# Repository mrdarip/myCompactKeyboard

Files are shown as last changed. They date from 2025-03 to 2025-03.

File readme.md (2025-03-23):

# my compact keyboard

## Description

## PCB
Here are pictures of my pcb:

| **Schematic** | **PCB** |
|---|---|
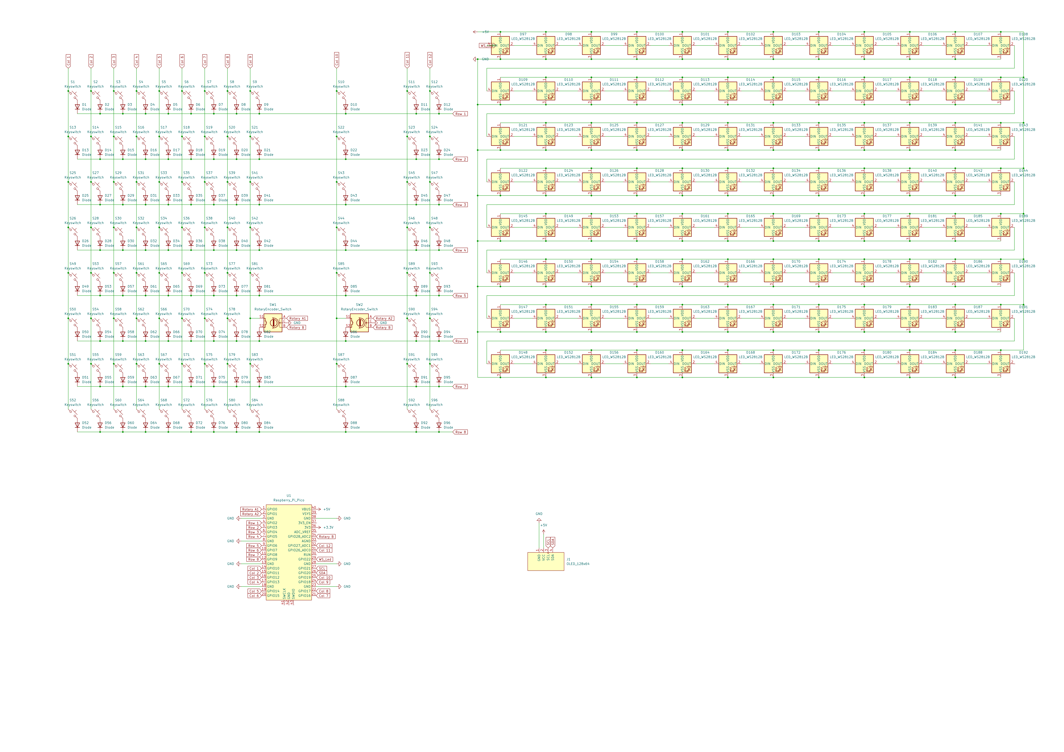
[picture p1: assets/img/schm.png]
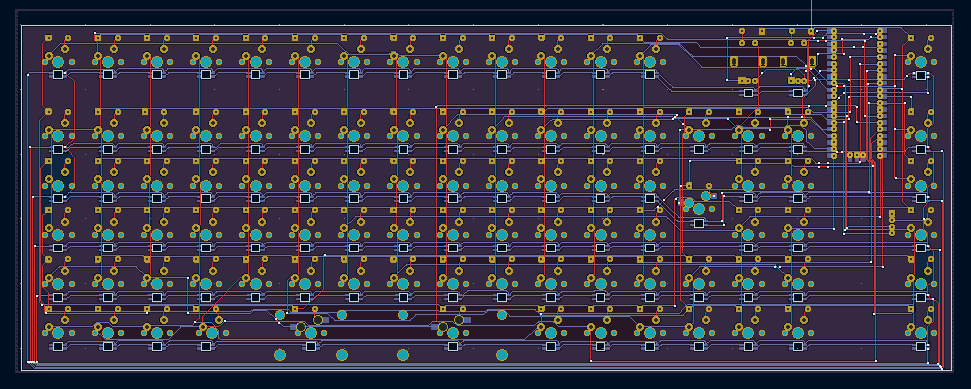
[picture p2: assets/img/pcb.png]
|||

Hope it looks good to you!

[x] I ran DRC and there are 0 errors

## CAD
Designed cases for it but my definitive one is made using svg's and openSCAD.

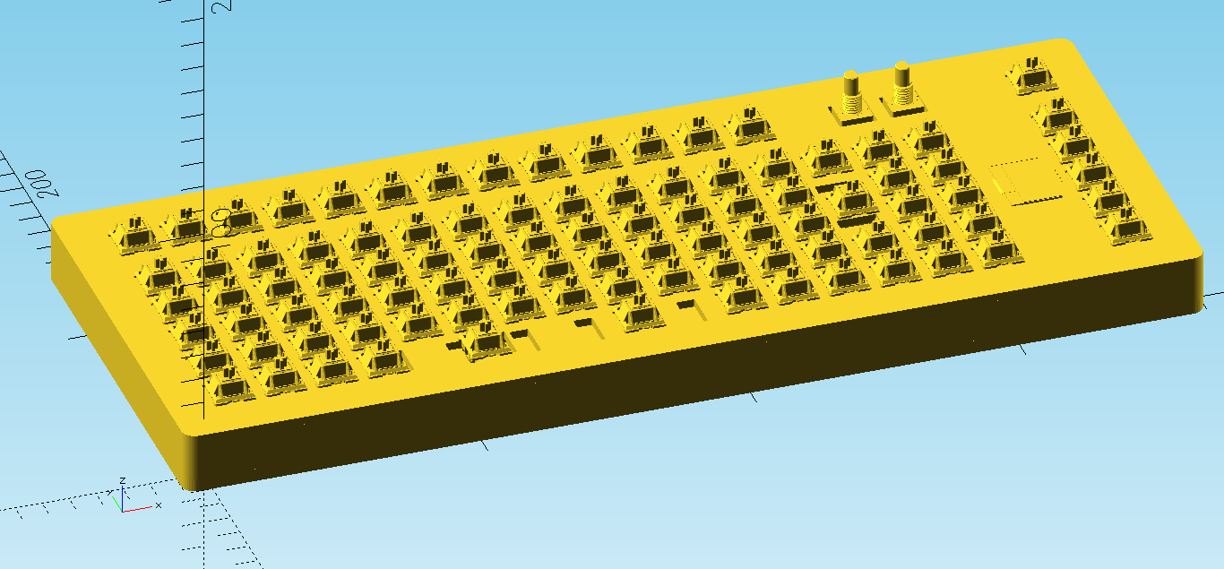
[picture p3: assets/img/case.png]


## Firmware

I wrote the firmware using kmk, it's pretty simple, but I'm proud of it!

## BOM
| **Quantity** | **Item** |
|---|---|
| 1 | Raspberry Pi Pico |
| 91 | Switches |
| 3 | Hotwap sockets |
| 96 | 1N4148 diodes |
| 96 | LED_WS2812B |
| 1 | SSD1306 |
| 2 | Rotary encoder |
| 1 | keycaps set |
| 3 | stabilizers |
| 4 | heatset inserts and their screws |

## IMPORTANT

- Dont send the 3d printed case  
    I'll print it myself so I'll get less customs fees.
- Don't send the soldering iron  
  I have one, less electronics waste, less customs fees.

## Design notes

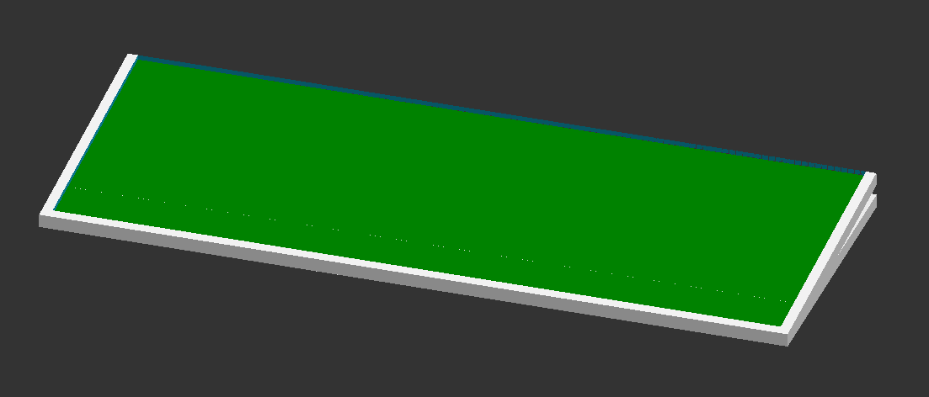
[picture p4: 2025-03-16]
assets/img/case2.png

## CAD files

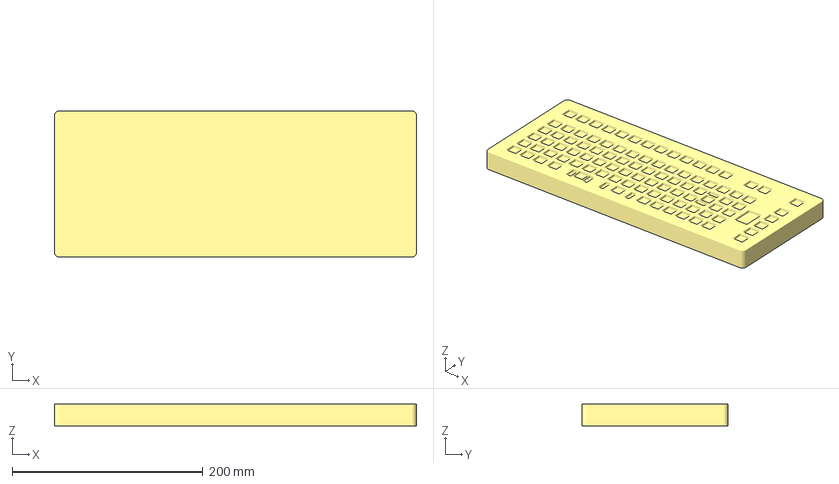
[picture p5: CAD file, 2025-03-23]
cad/caseByLayers.3mf
379.6 x 153.3 x 23.0 mm

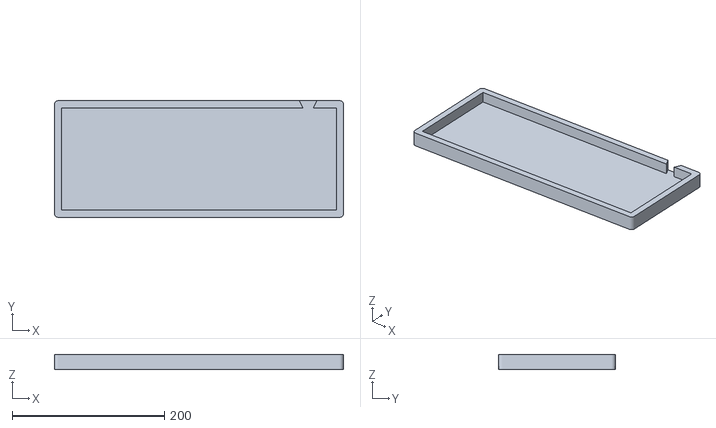
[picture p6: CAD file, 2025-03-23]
production/bottom.stl
379.6 x 153.3 x 20.0

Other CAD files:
pcb/freecadCase.FCStd
cad/case.scad
cad/caseByLayers.scad

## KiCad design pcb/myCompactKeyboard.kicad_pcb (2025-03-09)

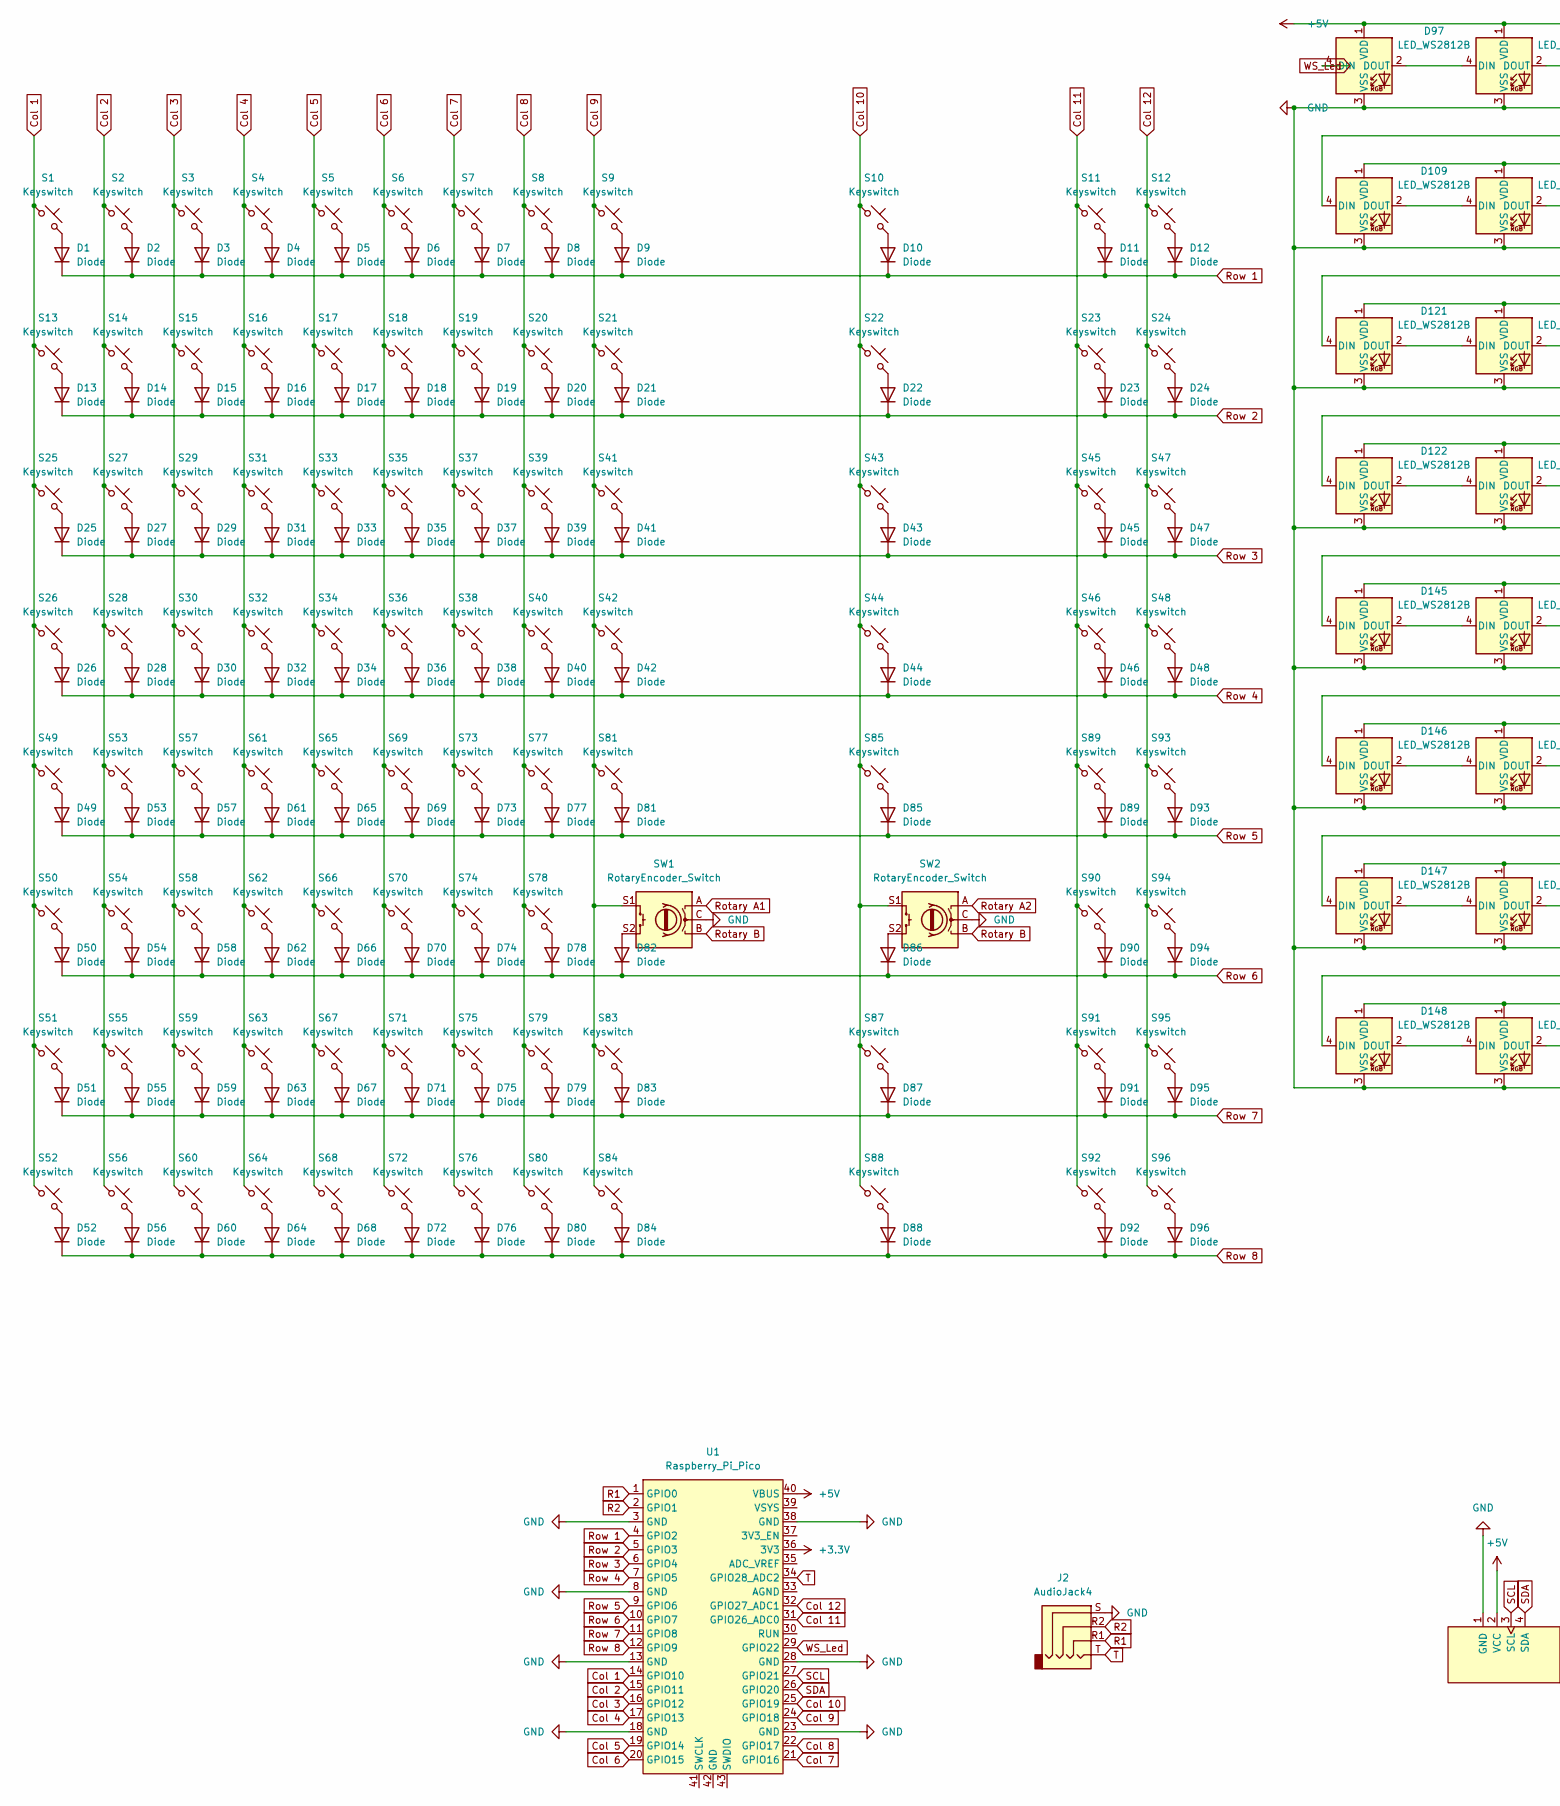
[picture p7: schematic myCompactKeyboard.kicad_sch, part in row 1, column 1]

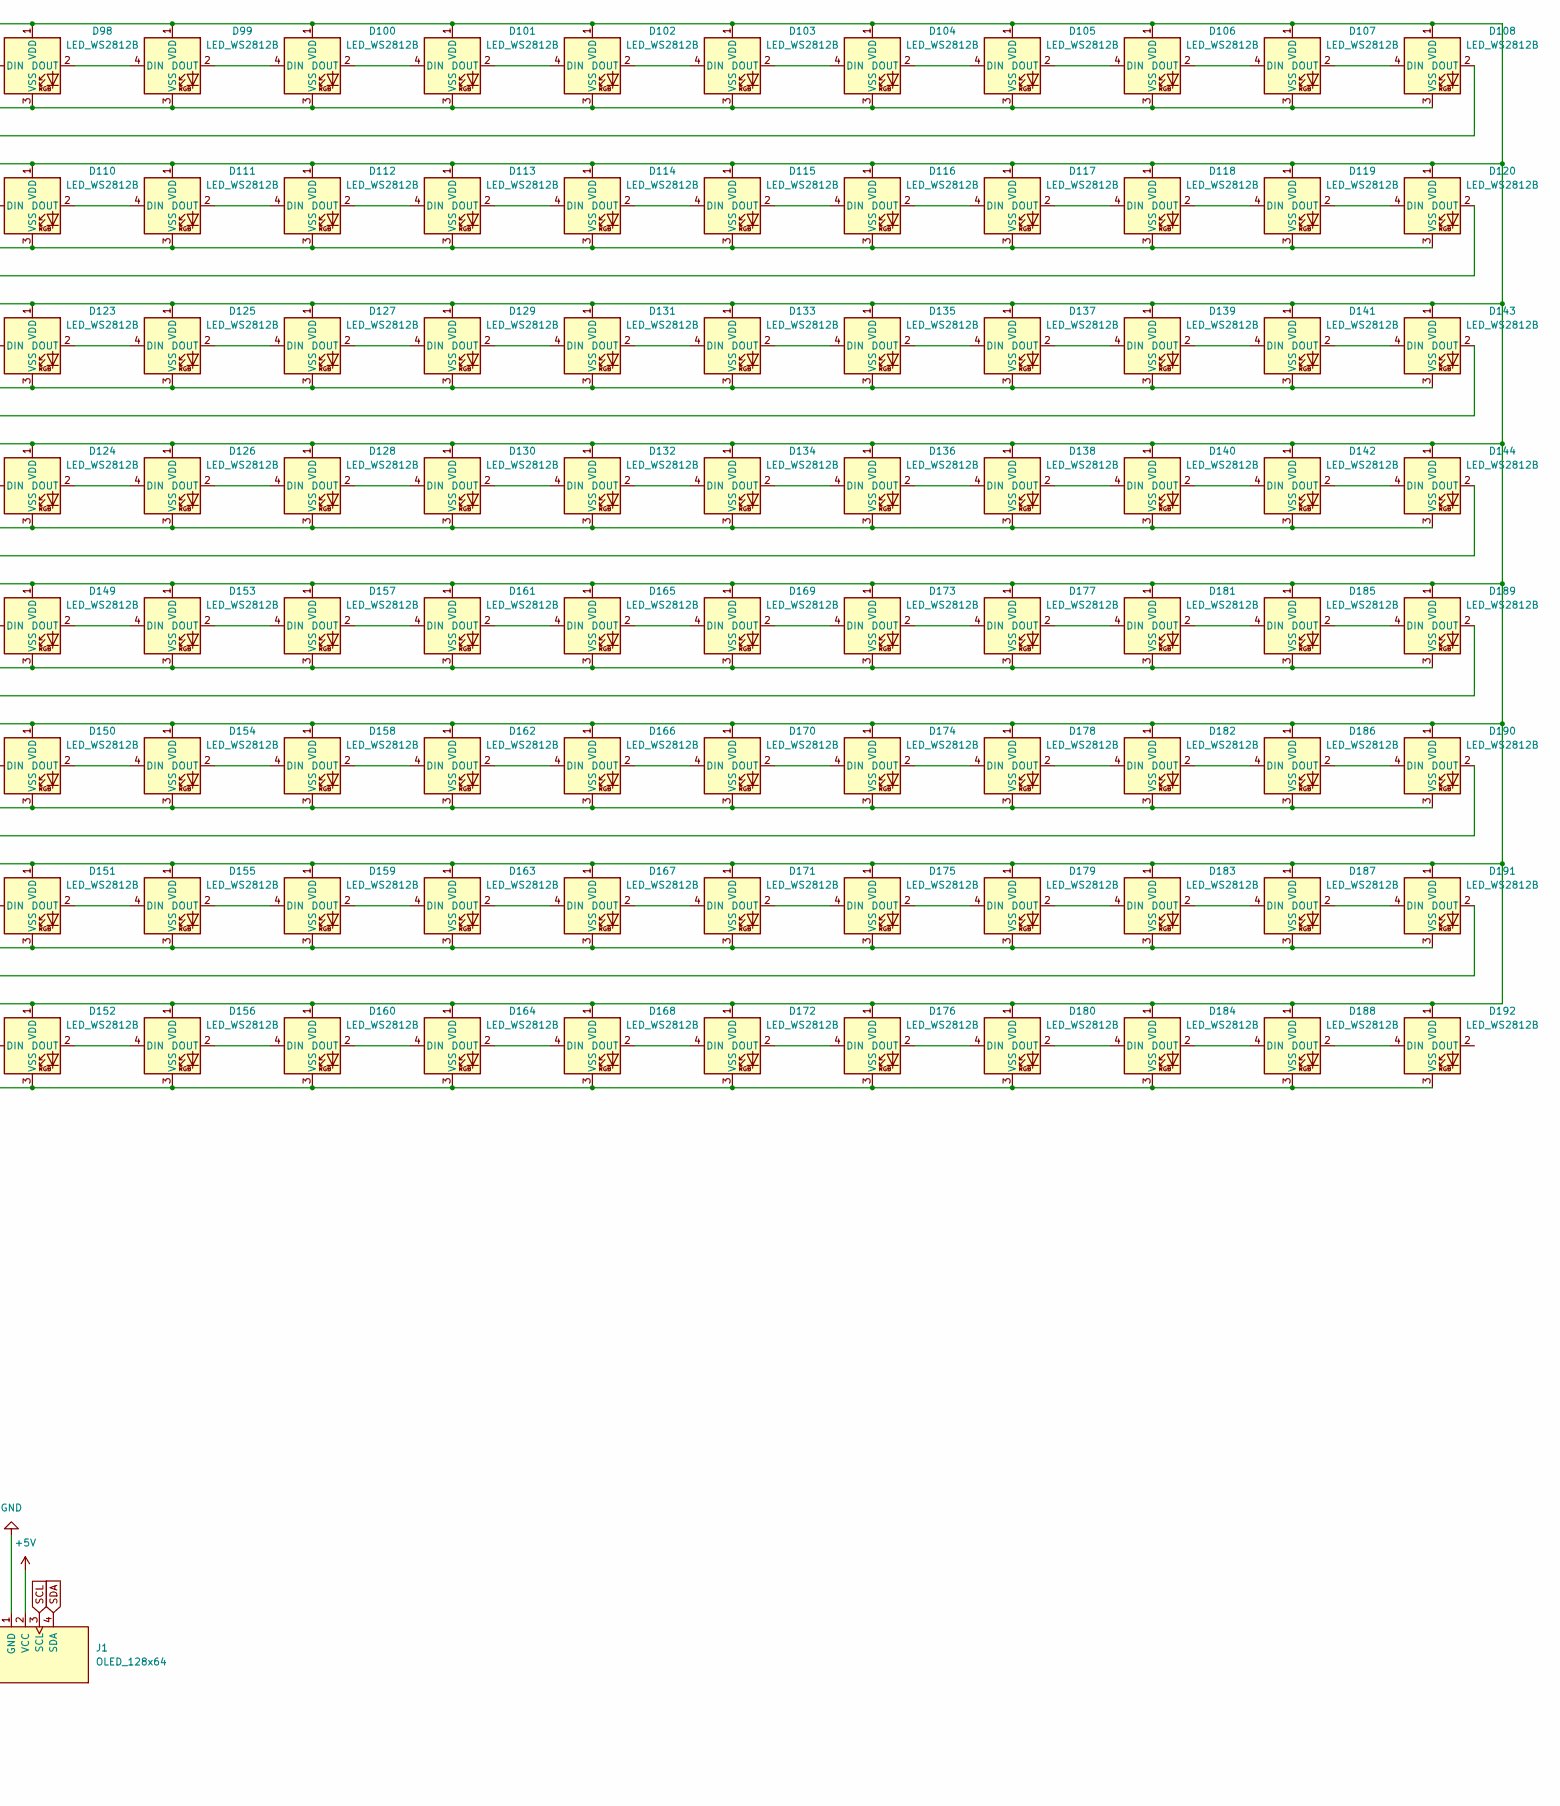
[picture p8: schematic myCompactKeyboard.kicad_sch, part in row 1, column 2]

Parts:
D1, D2, D3, D4, D5, D6, D7, D8, D9, D10, D11, D12, D13, D14, D15, D16, D17, D18, D19, D20, D21, D22, D23, D24, D25, D26, D27, D28, D29, D30, D31, D32, D33, D34, D35, D36, D37, D38, D39, D40, D41, D42, D43, D44, D45, D46, D47, D48, D49, D50, D51, D52, D53, D54, D55, D56, D57, D58, D59, D60, D61, D62, D63, D64, D65, D66, D67, D68, D69, D70, D71, D72, D73, D74, D75, D76, D77, D78, D79, D80, D81, D82, D83, D84, D85, D86, D87, D88, D89, D90, D91, D92, D93, D94, D95, D96: Diode; Diode_DO-35
D97, D98, D99, D100, D101, D102, D103, D104, D105, D106, D107, D108, D109, D110, D111, D112, D113, D114, D115, D116, D117, D118, D119, D120, D121, D122, D123, D124, D125, D126, D127, D128, D129, D130, D131, D132, D133, D134, D135, D136, D137, D138, D139, D140, D141, D142, D143, D144, D145, D146, D147, D148, D149, D150, D151, D152, D153, D154, D155, D156, D157, D158, D159, D160, D161, D162, D163, D164, D165, D166, D167, D168, D169, D170, D171, D172, D173, D174, D175, D176, D177, D178, D179, D180, D181, D182, D183, D184, D185, D186, D187, D188, D189, D190, D191, D192: LED_WS2812B; SK6812MINI-E
J1: OLED_128x64
J2: AudioJack4; Jack_3.5mm_CUI_SJ1-3524N_Horizontal
S1, S2, S3, S4, S5, S6, S7, S8, S9, S10, S11, S12, S13, S14, S15, S16, S17, S18, S19, S20, S21, S22, S23, S24, S25, S26, S27, S28, S29, S30, S31, S32, S33, S34, S35, S36, S37, S38, S39, S40, S41, S42, S43, S44, S45, S46, S47, S48, S49, S50, S51, S52, S53, S54, S55, S56, S57, S58, S59, S60, S61, S62, S63, S64, S65, S66, S67, S68, S69, S70, S71, S72, S73, S74, S75, S76, S77, S78, S79, S80, S81, S83, S84, S85, S87, S88, S89, S90, S91, S92, S93, S94, S95, S96: Keyswitch; MX_PCB_1.00u
SW1, SW2: RotaryEncoder_Switch; RotaryEncoder_Alps_EC11E-Switch_Vertical_H20mm
U1: Raspberry_Pi_Pico

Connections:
+3.3V: U1.36 (3V3)
+5V: D97.1 (VDD), D98.1 (VDD), D99.1 (VDD), D100.1 (VDD), D101.1 (VDD), D102.1 (VDD), D103.1 (VDD), D104.1 (VDD), D105.1 (VDD), D106.1 (VDD), D107.1 (VDD), D108.1 (VDD), D109.1 (VDD), D110.1 (VDD), D111.1 (VDD), D112.1 (VDD), D113.1 (VDD), D114.1 (VDD), D115.1 (VDD), D116.1 (VDD), D117.1 (VDD), D118.1 (VDD), D119.1 (VDD), D120.1 (VDD), D121.1 (VDD), D122.1 (VDD), D123.1 (VDD), D124.1 (VDD), D125.1 (VDD), D126.1 (VDD), D127.1 (VDD), D128.1 (VDD), D129.1 (VDD), D130.1 (VDD), D131.1 (VDD), D132.1 (VDD), D133.1 (VDD), D134.1 (VDD), D135.1 (VDD), D136.1 (VDD), D137.1 (VDD), D138.1 (VDD), D139.1 (VDD), D140.1 (VDD), D141.1 (VDD), D142.1 (VDD), D143.1 (VDD), D144.1 (VDD), D145.1 (VDD), D146.1 (VDD), D147.1 (VDD), D148.1 (VDD), D149.1 (VDD), D150.1 (VDD), D151.1 (VDD), D152.1 (VDD), D153.1 (VDD), D154.1 (VDD), D155.1 (VDD), D156.1 (VDD), D157.1 (VDD), D158.1 (VDD), D159.1 (VDD), D160.1 (VDD), D161.1 (VDD), D162.1 (VDD), D163.1 (VDD), D164.1 (VDD), D165.1 (VDD), D166.1 (VDD), D167.1 (VDD), D168.1 (VDD), D169.1 (VDD), D170.1 (VDD), D171.1 (VDD), D172.1 (VDD), D173.1 (VDD), D174.1 (VDD), D175.1 (VDD), D176.1 (VDD), D177.1 (VDD), D178.1 (VDD), D179.1 (VDD), D180.1 (VDD), D181.1 (VDD), D182.1 (VDD), D183.1 (VDD), D184.1 (VDD), D185.1 (VDD), D186.1 (VDD), D187.1 (VDD), D188.1 (VDD), D189.1 (VDD), D190.1 (VDD), D191.1 (VDD), D192.1 (VDD), J1.2 (VCC), U1.40 (VBUS)
Col 1: S1.1, S13.1, S25.1, S26.1, S49.1, S50.1, S51.1, S52.1, U1.14 (GPIO10)
Col 2: S2.1, S14.1, S27.1, S28.1, S53.1, S54.1, S55.1, S56.1, U1.15 (GPIO11)
Col 3: S3.1, S15.1, S29.1, S30.1, S57.1, S58.1, S59.1, S60.1, U1.16 (GPIO12)
Col 4: S4.1, S16.1, S31.1, S32.1, S61.1, S62.1, S63.1, S64.1, U1.17 (GPIO13)
Col 5: S5.1, S17.1, S33.1, S34.1, S65.1, S66.1, S67.1, S68.1, U1.19 (GPIO14)
Col 6: S6.1, S18.1, S35.1, S36.1, S69.1, S70.1, S71.1, S72.1, U1.20 (GPIO15)
Col 7: S7.1, S19.1, S37.1, S38.1, S73.1, S74.1, S75.1, S76.1, U1.21 (GPIO16)
Col 8: S8.1, S20.1, S39.1, S40.1, S77.1, S78.1, S79.1, S80.1, U1.22 (GPIO17)
Col 9: S9.1, S21.1, S41.1, S42.1, S81.1, S83.1, S84.1, SW1.S1, U1.24 (GPIO18)
Col 10: S10.1, S22.1, S43.1, S44.1, S85.1, S87.1, S88.1, SW2.S1, U1.25 (GPIO19)
Col 11: S11.1, S23.1, S45.1, S46.1, S89.1, S90.1, S91.1, S92.1, U1.31 (GPIO26_ADC0)
Col 12: S12.1, S24.1, S47.1, S48.1, S93.1, S94.1, S95.1, S96.1, U1.32 (GPIO27_ADC1)
GND: D97.3 (VSS), D98.3 (VSS), D99.3 (VSS), D100.3 (VSS), D101.3 (VSS), D102.3 (VSS), D103.3 (VSS), D104.3 (VSS), D105.3 (VSS), D106.3 (VSS), D107.3 (VSS), D108.3 (VSS), D109.3 (VSS), D110.3 (VSS), D111.3 (VSS), D112.3 (VSS), D113.3 (VSS), D114.3 (VSS), D115.3 (VSS), D116.3 (VSS), D117.3 (VSS), D118.3 (VSS), D119.3 (VSS), D120.3 (VSS), D121.3 (VSS), D122.3 (VSS), D123.3 (VSS), D124.3 (VSS), D125.3 (VSS), D126.3 (VSS), D127.3 (VSS), D128.3 (VSS), D129.3 (VSS), D130.3 (VSS), D131.3 (VSS), D132.3 (VSS), D133.3 (VSS), D134.3 (VSS), D135.3 (VSS), D136.3 (VSS), D137.3 (VSS), D138.3 (VSS), D139.3 (VSS), D140.3 (VSS), D141.3 (VSS), D142.3 (VSS), D143.3 (VSS), D144.3 (VSS), D145.3 (VSS), D146.3 (VSS), D147.3 (VSS), D148.3 (VSS), D149.3 (VSS), D150.3 (VSS), D151.3 (VSS), D152.3 (VSS), D153.3 (VSS), D154.3 (VSS), D155.3 (VSS), D156.3 (VSS), D157.3 (VSS), D158.3 (VSS), D159.3 (VSS), D160.3 (VSS), D161.3 (VSS), D162.3 (VSS), D163.3 (VSS), D164.3 (VSS), D165.3 (VSS), D166.3 (VSS), D167.3 (VSS), D168.3 (VSS), D169.3 (VSS), D170.3 (VSS), D171.3 (VSS), D172.3 (VSS), D173.3 (VSS), D174.3 (VSS), D175.3 (VSS), D176.3 (VSS), D177.3 (VSS), D178.3 (VSS), D179.3 (VSS), D180.3 (VSS), D181.3 (VSS), D182.3 (VSS), D183.3 (VSS), D184.3 (VSS), D185.3 (VSS), D186.3 (VSS), D187.3 (VSS), D188.3 (VSS), D189.3 (VSS), D190.3 (VSS), D191.3 (VSS), D192.3 (VSS), J1.1 (GND), J2.S, SW1.C, SW2.C, U1.3 (GND), U1.8 (GND), U1.13 (GND), U1.18 (GND), U1.23 (GND), U1.28 (GND), U1.38 (GND)
unnamed: D1.2 (A), S1.2
unnamed: D2.2 (A), S2.2
unnamed: D3.2 (A), S3.2
unnamed: D4.2 (A), S4.2
unnamed: D5.2 (A), S5.2
unnamed: D6.2 (A), S6.2
unnamed: D7.2 (A), S7.2
unnamed: D8.2 (A), S8.2
unnamed: D9.2 (A), S9.2
unnamed: D10.2 (A), S10.2
unnamed: D11.2 (A), S11.2
unnamed: D12.2 (A), S12.2
unnamed: D13.2 (A), S13.2
unnamed: D14.2 (A), S14.2
unnamed: D15.2 (A), S15.2
unnamed: D16.2 (A), S16.2
unnamed: D17.2 (A), S17.2
unnamed: D18.2 (A), S18.2
unnamed: D19.2 (A), S19.2
unnamed: D20.2 (A), S20.2
unnamed: D21.2 (A), S21.2
unnamed: D22.2 (A), S22.2
unnamed: D23.2 (A), S23.2
unnamed: D24.2 (A), S24.2
unnamed: D25.2 (A), S25.2
unnamed: D26.2 (A), S26.2
unnamed: D27.2 (A), S27.2
unnamed: D28.2 (A), S28.2
unnamed: D29.2 (A), S29.2
unnamed: D30.2 (A), S30.2
unnamed: D31.2 (A), S31.2
unnamed: D32.2 (A), S32.2
unnamed: D33.2 (A), S33.2
unnamed: D34.2 (A), S34.2
unnamed: D35.2 (A), S35.2
unnamed: D36.2 (A), S36.2
unnamed: D37.2 (A), S37.2
unnamed: D38.2 (A), S38.2
unnamed: D39.2 (A), S39.2
unnamed: D40.2 (A), S40.2
unnamed: D41.2 (A), S41.2
unnamed: D42.2 (A), S42.2
unnamed: D43.2 (A), S43.2
unnamed: D44.2 (A), S44.2
unnamed: D45.2 (A), S45.2
unnamed: D46.2 (A), S46.2
unnamed: D47.2 (A), S47.2
unnamed: D48.2 (A), S48.2
unnamed: D49.2 (A), S49.2
unnamed: D50.2 (A), S50.2
unnamed: D51.2 (A), S51.2
unnamed: D52.2 (A), S52.2
unnamed: D53.2 (A), S53.2
unnamed: D54.2 (A), S54.2
unnamed: D55.2 (A), S55.2
unnamed: D56.2 (A), S56.2
unnamed: D57.2 (A), S57.2
unnamed: D58.2 (A), S58.2
unnamed: D59.2 (A), S59.2
unnamed: D60.2 (A), S60.2
unnamed: D61.2 (A), S61.2
unnamed: D62.2 (A), S62.2
unnamed: D63.2 (A), S63.2
unnamed: D64.2 (A), S64.2
unnamed: D65.2 (A), S65.2
unnamed: D66.2 (A), S66.2
unnamed: D67.2 (A), S67.2
unnamed: D68.2 (A), S68.2
unnamed: D69.2 (A), S69.2
unnamed: D70.2 (A), S70.2
unnamed: D71.2 (A), S71.2
unnamed: D72.2 (A), S72.2
unnamed: D73.2 (A), S73.2
unnamed: D74.2 (A), S74.2
unnamed: D75.2 (A), S75.2
unnamed: D76.2 (A), S76.2
unnamed: D77.2 (A), S77.2
unnamed: D78.2 (A), S78.2
unnamed: D79.2 (A), S79.2
unnamed: D80.2 (A), S80.2
unnamed: D81.2 (A), S81.2
unnamed: D82.2 (A), SW1.S2
unnamed: D83.2 (A), S83.2
unnamed: D84.2 (A), S84.2
unnamed: D85.2 (A), S85.2
unnamed: D86.2 (A), SW2.S2
unnamed: D87.2 (A), S87.2
unnamed: D88.2 (A), S88.2
unnamed: D89.2 (A), S89.2
unnamed: D90.2 (A), S90.2
unnamed: D91.2 (A), S91.2
unnamed: D92.2 (A), S92.2
unnamed: D93.2 (A), S93.2
unnamed: D94.2 (A), S94.2
unnamed: D95.2 (A), S95.2
unnamed: D96.2 (A), S96.2
unnamed: D97.2 (DOUT), D98.4 (DIN)
unnamed: D98.2 (DOUT), D99.4 (DIN)
unnamed: D99.2 (DOUT), D100.4 (DIN)
unnamed: D100.2 (DOUT), D101.4 (DIN)
unnamed: D101.2 (DOUT), D102.4 (DIN)
unnamed: D102.2 (DOUT), D103.4 (DIN)
unnamed: D103.2 (DOUT), D104.4 (DIN)
unnamed: D104.2 (DOUT), D105.4 (DIN)
unnamed: D105.2 (DOUT), D106.4 (DIN)
unnamed: D106.2 (DOUT), D107.4 (DIN)
unnamed: D107.2 (DOUT), D108.4 (DIN)
unnamed: D108.2 (DOUT), D109.4 (DIN)
unnamed: D109.2 (DOUT), D110.4 (DIN)
unnamed: D110.2 (DOUT), D111.4 (DIN)
unnamed: D111.2 (DOUT), D112.4 (DIN)
unnamed: D112.2 (DOUT), D113.4 (DIN)
unnamed: D113.2 (DOUT), D114.4 (DIN)
unnamed: D114.2 (DOUT), D115.4 (DIN)
unnamed: D115.2 (DOUT), D116.4 (DIN)
unnamed: D116.2 (DOUT), D117.4 (DIN)
unnamed: D117.2 (DOUT), D118.4 (DIN)
unnamed: D118.2 (DOUT), D119.4 (DIN)
unnamed: D119.2 (DOUT), D120.4 (DIN)
unnamed: D120.2 (DOUT), D121.4 (DIN)
unnamed: D121.2 (DOUT), D123.4 (DIN)
unnamed: D122.4 (DIN), D143.2 (DOUT)
unnamed: D122.2 (DOUT), D124.4 (DIN)
unnamed: D123.2 (DOUT), D125.4 (DIN)
unnamed: D124.2 (DOUT), D126.4 (DIN)
unnamed: D125.2 (DOUT), D127.4 (DIN)
unnamed: D126.2 (DOUT), D128.4 (DIN)
unnamed: D127.2 (DOUT), D129.4 (DIN)
unnamed: D128.2 (DOUT), D130.4 (DIN)
unnamed: D129.2 (DOUT), D131.4 (DIN)
unnamed: D130.2 (DOUT), D132.4 (DIN)
unnamed: D131.2 (DOUT), D133.4 (DIN)
unnamed: D132.2 (DOUT), D134.4 (DIN)
unnamed: D133.2 (DOUT), D135.4 (DIN)
unnamed: D134.2 (DOUT), D136.4 (DIN)
unnamed: D135.2 (DOUT), D137.4 (DIN)
unnamed: D136.2 (DOUT), D138.4 (DIN)
unnamed: D137.2 (DOUT), D139.4 (DIN)
unnamed: D138.2 (DOUT), D140.4 (DIN)
unnamed: D139.2 (DOUT), D141.4 (DIN)
unnamed: D140.2 (DOUT), D142.4 (DIN)
unnamed: D141.2 (DOUT), D143.4 (DIN)
unnamed: D142.2 (DOUT), D144.4 (DIN)
unnamed: D144.2 (DOUT), D145.4 (DIN)
unnamed: D145.2 (DOUT), D149.4 (DIN)
unnamed: D146.4 (DIN), D189.2 (DOUT)
unnamed: D146.2 (DOUT), D150.4 (DIN)
unnamed: D147.4 (DIN), D190.2 (DOUT)
unnamed: D147.2 (DOUT), D151.4 (DIN)
unnamed: D148.4 (DIN), D191.2 (DOUT)
unnamed: D148.2 (DOUT), D152.4 (DIN)
unnamed: D149.2 (DOUT), D153.4 (DIN)
unnamed: D150.2 (DOUT), D154.4 (DIN)
unnamed: D151.2 (DOUT), D155.4 (DIN)
unnamed: D152.2 (DOUT), D156.4 (DIN)
unnamed: D153.2 (DOUT), D157.4 (DIN)
unnamed: D154.2 (DOUT), D158.4 (DIN)
unnamed: D155.2 (DOUT), D159.4 (DIN)
unnamed: D156.2 (DOUT), D160.4 (DIN)
unnamed: D157.2 (DOUT), D161.4 (DIN)
unnamed: D158.2 (DOUT), D162.4 (DIN)
unnamed: D159.2 (DOUT), D163.4 (DIN)
unnamed: D160.2 (DOUT), D164.4 (DIN)
unnamed: D161.2 (DOUT), D165.4 (DIN)
unnamed: D162.2 (DOUT), D166.4 (DIN)
unnamed: D163.2 (DOUT), D167.4 (DIN)
unnamed: D164.2 (DOUT), D168.4 (DIN)
unnamed: D165.2 (DOUT), D169.4 (DIN)
unnamed: D166.2 (DOUT), D170.4 (DIN)
unnamed: D167.2 (DOUT), D171.4 (DIN)
unnamed: D168.2 (DOUT), D172.4 (DIN)
unnamed: D169.2 (DOUT), D173.4 (DIN)
unnamed: D170.2 (DOUT), D174.4 (DIN)
unnamed: D171.2 (DOUT), D175.4 (DIN)
unnamed: D172.2 (DOUT), D176.4 (DIN)
unnamed: D173.2 (DOUT), D177.4 (DIN)
unnamed: D174.2 (DOUT), D178.4 (DIN)
unnamed: D175.2 (DOUT), D179.4 (DIN)
unnamed: D176.2 (DOUT), D180.4 (DIN)
unnamed: D177.2 (DOUT), D181.4 (DIN)
unnamed: D178.2 (DOUT), D182.4 (DIN)
unnamed: D179.2 (DOUT), D183.4 (DIN)
unnamed: D180.2 (DOUT), D184.4 (DIN)
unnamed: D181.2 (DOUT), D185.4 (DIN)
unnamed: D182.2 (DOUT), D186.4 (DIN)
unnamed: D183.2 (DOUT), D187.4 (DIN)
unnamed: D184.2 (DOUT), D188.4 (DIN)
unnamed: D185.2 (DOUT), D189.4 (DIN)
unnamed: D186.2 (DOUT), D190.4 (DIN)
unnamed: D187.2 (DOUT), D191.4 (DIN)
unnamed: D188.2 (DOUT), D192.4 (DIN)
R1: J2.R1, U1.1 (GPIO0)
R2: J2.R2, U1.2 (GPIO1)
Rotary A1: SW1.A
Rotary A2: SW2.A
Rotary B: SW1.B, SW2.B
Row 1: D1.1 (K), D2.1 (K), D3.1 (K), D4.1 (K), D5.1 (K), D6.1 (K), D7.1 (K), D8.1 (K), D9.1 (K), D10.1 (K), D11.1 (K), D12.1 (K), U1.4 (GPIO2)
Row 2: D13.1 (K), D14.1 (K), D15.1 (K), D16.1 (K), D17.1 (K), D18.1 (K), D19.1 (K), D20.1 (K), D21.1 (K), D22.1 (K), D23.1 (K), D24.1 (K), U1.5 (GPIO3)
Row 3: D25.1 (K), D27.1 (K), D29.1 (K), D31.1 (K), D33.1 (K), D35.1 (K), D37.1 (K), D39.1 (K), D41.1 (K), D43.1 (K), D45.1 (K), D47.1 (K), U1.6 (GPIO4)
Row 4: D26.1 (K), D28.1 (K), D30.1 (K), D32.1 (K), D34.1 (K), D36.1 (K), D38.1 (K), D40.1 (K), D42.1 (K), D44.1 (K), D46.1 (K), D48.1 (K), U1.7 (GPIO5)
Row 5: D49.1 (K), D53.1 (K), D57.1 (K), D61.1 (K), D65.1 (K), D69.1 (K), D73.1 (K), D77.1 (K), D81.1 (K), D85.1 (K), D89.1 (K), D93.1 (K), U1.9 (GPIO6)
Row 6: D50.1 (K), D54.1 (K), D58.1 (K), D62.1 (K), D66.1 (K), D70.1 (K), D74.1 (K), D78.1 (K), D82.1 (K), D86.1 (K), D90.1 (K), D94.1 (K), U1.10 (GPIO7)
Row 7: D51.1 (K), D55.1 (K), D59.1 (K), D63.1 (K), D67.1 (K), D71.1 (K), D75.1 (K), D79.1 (K), D83.1 (K), D87.1 (K), D91.1 (K), D95.1 (K), U1.11 (GPIO8)
Row 8: D52.1 (K), D56.1 (K), D60.1 (K), D64.1 (K), D68.1 (K), D72.1 (K), D76.1 (K), D80.1 (K), D84.1 (K), D88.1 (K), D92.1 (K), D96.1 (K), U1.12 (GPIO9)
SCL: J1.3 (SCL), U1.27 (GPIO21)
SDA: J1.4 (SDA), U1.26 (GPIO20)
T: J2.T, U1.34 (GPIO28_ADC2)
WS_Led: D97.4 (DIN), U1.29 (GPIO22)

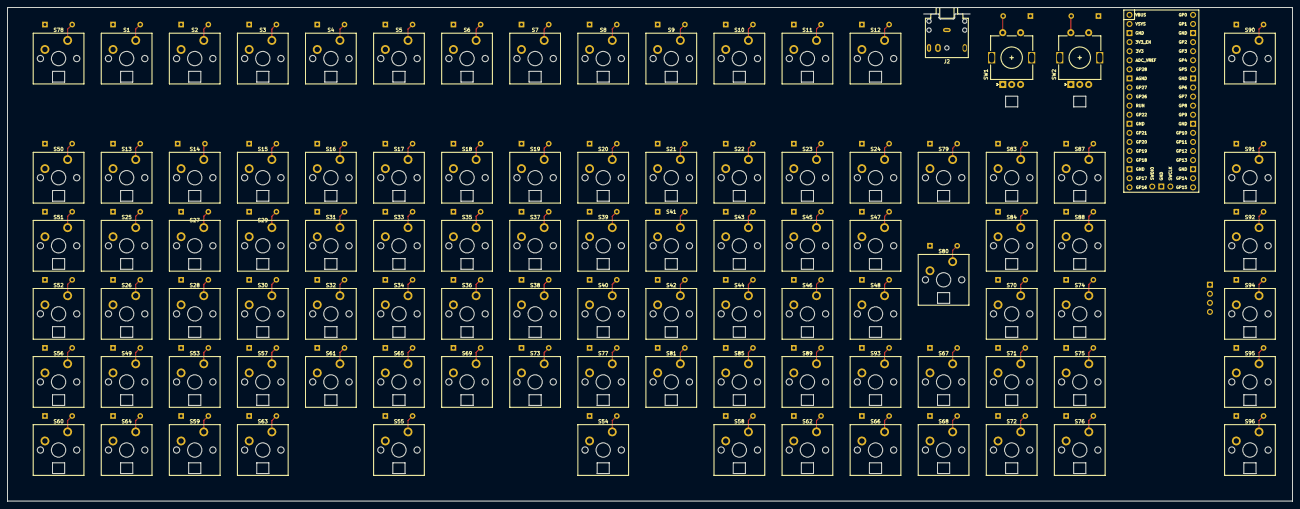
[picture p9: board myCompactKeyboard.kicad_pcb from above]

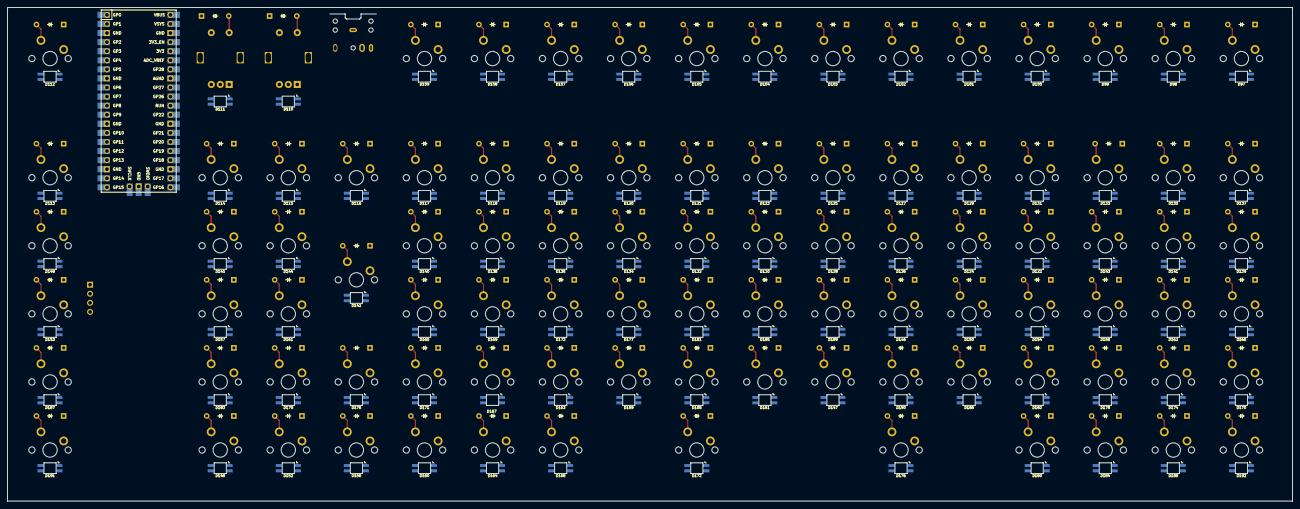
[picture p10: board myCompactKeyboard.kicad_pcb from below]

Board: 2 copper layers, 359.6 x 138.1 mm, 291 parts (193 on the bottom side), 218 nets.

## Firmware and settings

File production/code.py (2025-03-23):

from kmk.kmk_keyboard import KMKKeyboard
from kmk.scanners.keypad import MatrixScanner
from kmk.keys import KC
from kmk.modules.split import Split, SplitType
from kmk.modules.encoder import EncoderHandler
from kmk.modules.rgb import RGB
from kmk.modules.display import OledDisplay
import board
import digitalio
import neopixel
import adafruit_ssd1306

keyboard = KMKKeyboard()

# Configurar la matriz de teclas
keyboard.matrix = MatrixScanner(
    rows=[board.GP2, board.GP3, board.GP4, board.GP5, board.GP6, board.GP7, board.GP8, board.GP9],
    columns=[board.GP10, board.GP11, board.GP12, board.GP13, board.GP14, board.GP15, board.GP16, board.GP17, board.GP18, board.GP19, board.GP26, board.GP27],
    diode_orientation=MatrixScanner.DIODE_COL2ROW
)

# Configurar la pantalla OLED
WIDTH = 128
HEIGHT = 32
counter = 0

i2c = board.I2C()
display = adafruit_ssd1306.SSD1306_I2C(WIDTH, HEIGHT, i2c)
display.fill(0)
display.show()

def update_oled():
    display.fill(0)
    display.text(f'Counter: {counter}', 0, 0, 1)
    display.show()

# Configurar los LEDs RGB
NUM_LEDS = 96
pixels = neopixel.NeoPixel(board.GP22, NUM_LEDS, auto_write=False)
pixels.fill((0, 0, 0))
pixels.show()

def blink_led():
    led_index = counter % NUM_LEDS
    pixels[led_index] = (255, 255, 255)
    pixels.show()
    time.sleep(0.1)
    pixels[led_index] = (0, 0, 0)
    pixels.show()

# Configurar encoders
encoder_handler = EncoderHandler()
keyboard.modules.append(encoder_handler)

def rotary_callback(position, direction):
    global counter
    if direction == 1:
        counter += 1
        update_oled()
        blink_led()
    elif direction == -1:
        counter = max(0, counter - 1)
        update_oled()
        blink_led()

encoder_handler.pins = [(board.GP0, board.GP28), (board.GP28, board.GP1)]
encoder_handler.callbacks = [rotary_callback, rotary_callback]

# Definir las capas del teclado
keyboard.keymap = [
    [KC.F1, KC.F2, KC.F3, KC.F4, KC.F5, KC.F6, KC.F7, KC.F8, KC.F9, KC.F10, KC.F11, KC.F12],
    [KC.N1, KC.N2, KC.N3, KC.N4, KC.N5, KC.N6, KC.N7, KC.N8, KC.N9, KC.N0, KC.MINS, KC.EQL],
    [KC.Q, KC.W, KC.E, KC.R, KC.T, KC.Y, KC.U, KC.I, KC.O, KC.P, KC.LBRC, KC.RBRC],
    [KC.A, KC.S, KC.D, KC.F, KC.G, KC.H, KC.J, KC.K, KC.L, KC.SCLN, KC.QUOT, KC.BSLS],
    [KC.LSFT, KC.Z, KC.X, KC.C, KC.V, KC.B, KC.N, KC.M, KC.COMM, KC.DOT, KC.SLSH, KC.NO],
    [KC.GRV, KC.SPC, KC.RALT, KC.APP, KC.LCTL, KC.HOME, KC.END, KC.ESC, KC.NO, KC.NO, KC.NO, KC.NO],
    [KC.TAB, KC.SPC, KC.FN, KC.LALT, KC.NO, KC.UP, KC.NO, KC.LEFT, KC.PSCR, KC.PGUP, KC.NO, KC.NO],
    [KC.CAPS, KC.LSFT, KC.LCTL, KC.LGUI, KC.LEFT, KC.DOWN, KC.RIGHT, KC.ENTER, KC.DEL, KC.PGDN, KC.NO, KC.NO]
]

keyboard.go()

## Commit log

2025-03-06 added initial scheme layout
    [myCompactKeyboard.kicad_pcb, myCompactKeyboard.kicad_sch]
2025-03-06 switched layout to 8x12
    [myCompactKeyboard.kicad_sch]
2025-03-06 added the led matrix to the schematic
    [myCompactKeyboard.kicad_sch]
2025-03-06 wired the keys in the schematic
    [myCompactKeyboard.kicad_sch]
2025-03-07 converted the light matrix to a full 12x8
    [myCompactKeyboard.kicad_sch]
2025-03-07 added labels to switch matrix
    [myCompactKeyboard.kicad_sch]
2025-03-07 added labels to rotary encoders
    [myCompactKeyboard.kicad_sch]
2025-03-07 created pcb and placed switches
    [myCompactKeyboard.kicad_pcb, myCompactKeyboard.kicad_sch]
2025-03-07 placed diodes on pcb
    [myCompactKeyboard.kicad_pcb]
2025-03-08 placed all elements on pcb and started wiring
    [myCompactKeyboard.kicad_pcb, myCompactKeyboard.kicad_sch]
2025-03-08 fixed all components placement
    [myCompactKeyboard.kicad_pcb]
2025-03-08 positioned all Led on the pcb
    [myCompactKeyboard.kicad_pcb]
2025-03-08 flipped all diodes
    [myCompactKeyboard.kicad_pcb]
2025-03-09 added a jack conector
    [myCompactKeyboard.kicad_pcb, myCompactKeyboard.kicad_sch]
2025-03-09 wired all simple keyswitch connections
    [myCompactKeyboard.kicad_pcb, myCompactKeyboard.kicad_sch]
2025-03-09 added gnd pouring
2025-03-09 wired most horizontal connections
2025-03-09 wired most easy connections
2025-03-09 wired leds and most components
2025-03-10 repositioned all leds
2025-03-11 wired most leds net
2025-03-12 completed wiring with 1 drc error
2025-03-12 changed jack to smd and fixed all errors and many warnings
    [myCompactKeyboard.kicad_sch]
2025-03-13 added x.00u switches (instead of 1.00)
    [myCompactKeyboard.kicad_sch]
2025-03-15 moved half a row down top keys
    [myCompactKeyboard.kicad_sch]
2025-03-15 fixed hotswap keys and jack
    [myCompactKeyboard.kicad_sch]
2025-03-15 converted firs spacebar to 2.75u and alt to 1.25u
    [myCompactKeyboard.kicad_sch]
2025-03-16 added submission files
    [case.scad]
2025-03-18 starte creating case in freecad
    [freecadCase.FCStd]
2025-03-18 created all the case "layers" in inkscape
2025-03-19 created case with svg
    [caseByLayers.scad]
2025-03-23 completed and exported case
    [bottom.stl, caseByLayers.scad]
2025-03-23 remove jack and wire rotary encoders
    [myCompactKeyboard.kicad_sch]
2025-03-23 add caseByLayers.3mf file
    [caseByLayers.3mf]
